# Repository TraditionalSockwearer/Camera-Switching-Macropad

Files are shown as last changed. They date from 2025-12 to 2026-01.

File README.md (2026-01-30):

# Custom OBS Macropad (RP2040)





## Project Status: Completed

## Project Overview
This project is an ongoing engineering initiative to build a custom, 4-key mechanical macropad designed specifically for **Live OBS (Open Broadcaster Software) Scene Switching**.

**The Use Case:**
This device is being built for a local temple's media team. The goal is to provide volunteer operators with a simplified, fail-safe hardware interface to switch camera angles during live services, eliminating the need to interact with complex software UI during a broadcast.

## Planned Features
* **Context-Aware Display:** Integrated **0.91" OLED** to display active camera scenes ("Camera 1 Active", etc.).
* **Synced RGB Feedback:** 4x **SK6812 Mini-E LEDs** that provide colour-coded status indicators synchronised with the active scene.
* **USB HID Interface:** Acts as a standard keyboard sending F13-F16 keys to trigger OBS hotkeys.
* **Compact Form Factor:** Custom 3D-printed enclosure with heat-set inserts for durability.

## Tech Stack
* **Microcontroller:** Seeed Studio XIAO RP2040
* **EDA / PCB:** KiCad 9
* **CAD:** Fusion 360
* **Firmware:** Python (MicroPython) with State Machine logic.
* **Simulation:** Wokwi (Used to validate I2C OLED & NeoPixel logic) and onboard testing.

## Development Roadmap
- [x] **Requirement Analysis:** Defined constraints (silent switches, OLED feedback).
- [x] **Component Sourcing:** Validated BOM (Bill of Materials) for cost/availability.
- [x] **Schematic Capture:** Completed electrical schematic in KiCad.
- [x] **PCB Layout:** Routing tracks and defining edge cuts (In Progress).
- [x] **Prototyping:** 3D printing the case and soldering the first unit.
- [x] **Firmware Prototype:** Created state-machine logic in Wokwi (Simulation).
- [x] **Integration:** Final HID implementation and OBS setup at the venue.

## Repository Structure
```text
/CAD          # STL files (In Progress)
/PCB       # Schematic and PCB files
/Firmware     # Wokwi simulation code and future main.py
```

## CAD Model






Made in Fusion360

## PCB


## Schematic



# BOM

* 4x Cherry MX Switches 

* 2x SK6812 MINI Leds

SK6812 MINI-E RGB 20PCS Link: 

    https://www.aliexpress.com/item/1005008308801366.html

* 1x XIAO RP2040 

Seeed XIAO RP2040 Link: 

    https://www.aliexpress.com/item/1005008200917480.html

* 4x Blank DSA Keycaps

Blank Keycaps 10PCS Link: 
    
    https://www.aliexpress.com/item/1005005514406952.html

* 4x M3x16 Bolt 

M3x16mm Screw Link: 
    
    https://www.aliexpress.com/item/1005008585550992.html

* 4x M3 Heatset 

M3 Heat Set Link: 

    https://www.aliexpress.com/item/1005008897571758.html

* 1x 0.91" 128x32 OLED Display 

OLED Display Link: 

    https://www.aliexpress.com/item/1005008640108394.html

* 1x Case (2 parts: Bottom Case and Cover)

* 1x PCB

I used JLBPCB for PCB
Gerber files are made by opening pcb file. Then press the Files, then Plot, and make sure to press drill and as a single file (it's an option)

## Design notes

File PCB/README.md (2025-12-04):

# Requires Footprint
It is in .gitmodules. However, it doesn't upload so u need to add
Oled display

    https://github.com/gorbachev/KiCad-SSD1306-0.91-OLED-4pin-128x32.pretty/tree/master

Switches

    https://github.com/ai03-2725/MX_V2

OPL_Kicad_Libary

    https://github.com/Seeed-Studio/OPL_Kicad_Library

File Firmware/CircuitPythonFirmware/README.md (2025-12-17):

# The Firmware (KMK + Animated OLED + NeoPixels)
Firmware built on the **Seeed Studio XIAO RP2040** running **CircuitPython** and **KMK Firmware**. It features a 128x32 OLED screen that plays animations when keys are pressed and syncs RGB lighting to the active camera state (Green, Red, Blue, Yellow).

## Feature Status
- [x] **4-Key Matrix Scanning** (KMK Firmware)
- [x] **OLED Support** (SSD1306 via I2C at 0x3C)
- [x] **Custom Animation Extension** (Non-blocking background playback)
- [x] **Responsive Text** (Auto-centering text labels like "CAM 1")
- [x] **RGB LED Sync** (Smooth non-blocking color fades matching the camera state)
- [x] **Onboard LED Control** (Syncs XIAO onboard NeoPixel with external strip)

## Hardware
* **Microcontroller:** Seeed Studio XIAO RP2040
* **Display:** 0.91" OLED (SSD1306 Driver, 128x32 resolution)
* **LEDs:**
    * 1x Onboard WS2812 (NeoPixel)
    * 4x SK6812MINI-E (External Strip connected to Pin D6)
* **Switches:** 4x Mechanical Switches (Directly wired to Pins D0, D1, D2, D3)

## Libraries Used
The following libraries must be installed in the `lib` folder on your `CIRCUITPY` drive:

| Library | Purpose |
| :--- | :--- |
| **KMK Firmware** | Core keyboard firmware handling matrix scanning and keycodes. |
| **adafruit_displayio_ssd1306** | Driver for the OLED display. |
| **adafruit_display_text** | Handles text rendering and label positioning on screen. |
| **adafruit_bus_device** | Core I2C communication helper. |
| **neopixel** | Controls the addressable RGB LEDs. |

> **Note:** Using **CircuitPython 9.x or 10.x** requires built-in library `i2cdisplaybus`.

## 📂 File Structure
`CIRCUITPY` drive should look like this:

```text
CIRCUITPY/
├── lib/
│   ├── kmk/
│   ├── adafruit_display_text/
│   ├── adafruit_displayio_ssd1306.mpy
│   ├── adafruit_bus_device/
│   └── neopixel.mpy
├── code.py              # Main entry point (Keyboard setup)
├── movie_extension.py   # Custom extension for Animation & LEDs
└── movie_data.py        # Raw bitmap data for the animation

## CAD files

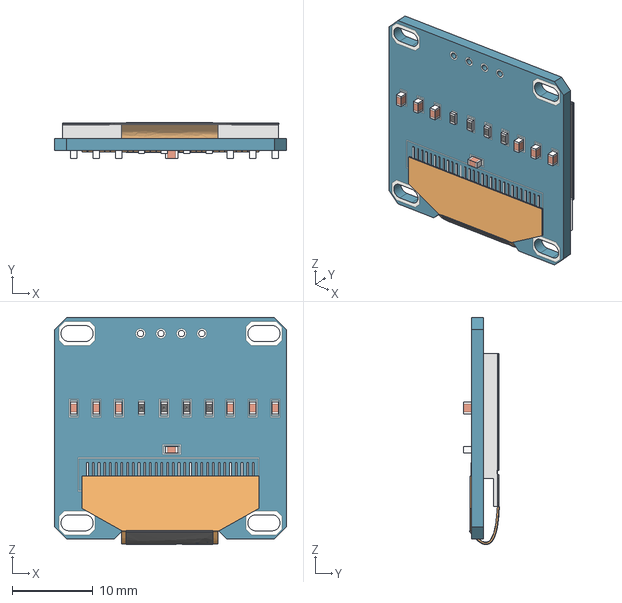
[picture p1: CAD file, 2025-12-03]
Case/Combined look/SSD1306.stp
28.8 x 4.46 x 28.2 mm

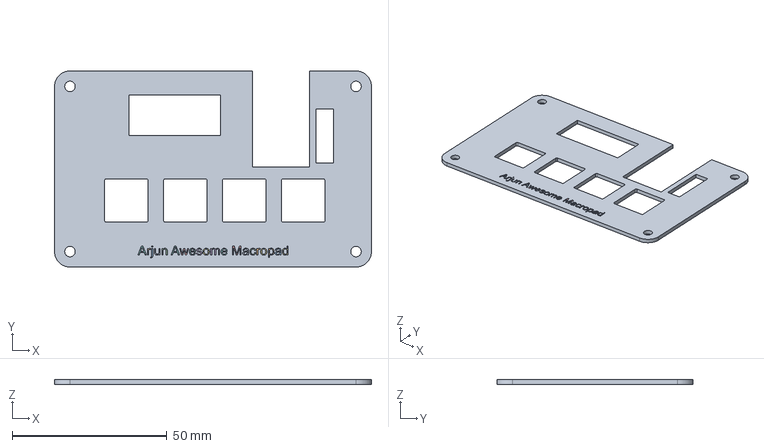
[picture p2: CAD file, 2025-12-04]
Case/The Shell/TopCase.step
102.4 x 63.4 x 1.50 mm

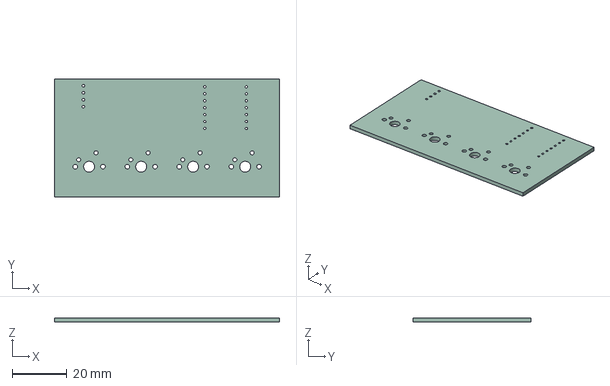
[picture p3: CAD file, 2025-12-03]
PCB/MyPCB.step
82.4 x 43.3 x 1.51 mm

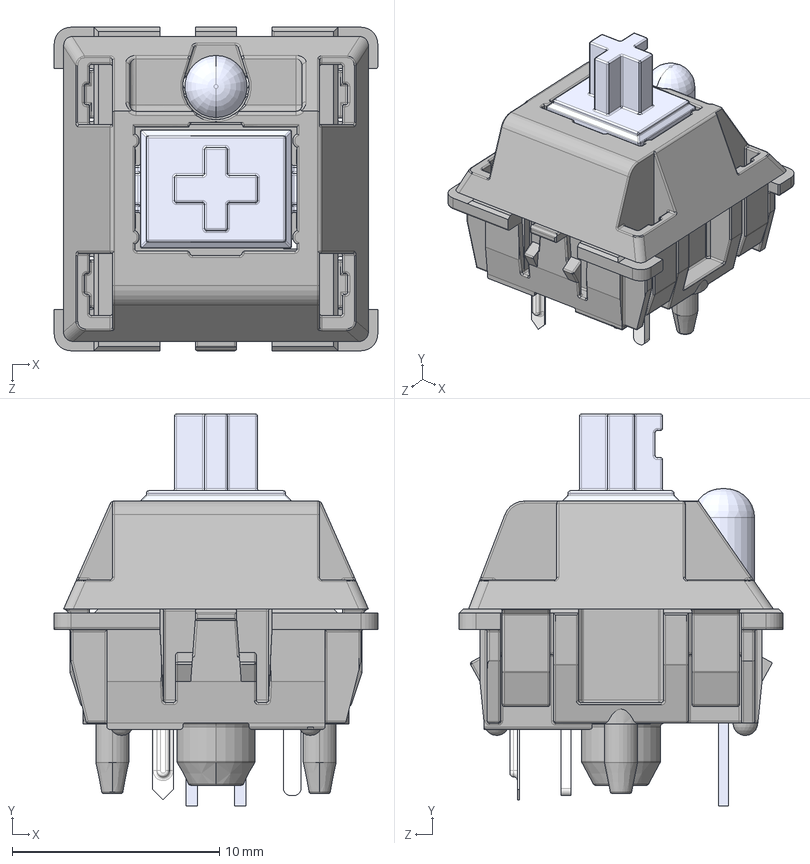
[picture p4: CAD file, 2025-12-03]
Case/Combined look/MX .STEP
15.6 x 18.9 x 15.6 mm
MX 轴 按键′_ü___¨1
MX 轴 轴体áì_¨￠¨__
MX粣 拸簽LEDLEDLED
MX轴 轴体 底部 μ×2__默认_á2____è_
针脚___默认__è_

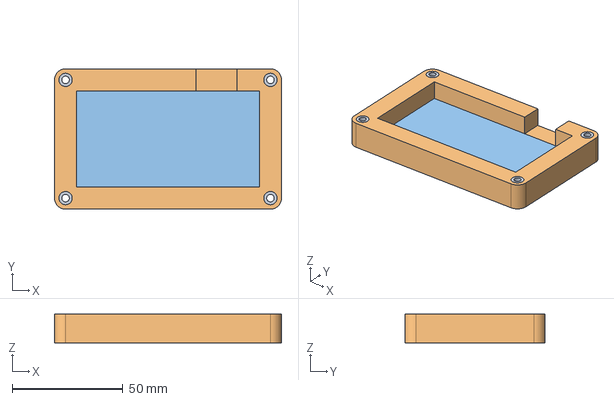
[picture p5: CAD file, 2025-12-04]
Case/The Shell/BottomCase.step
102.4 x 63.4 x 13.0 mm

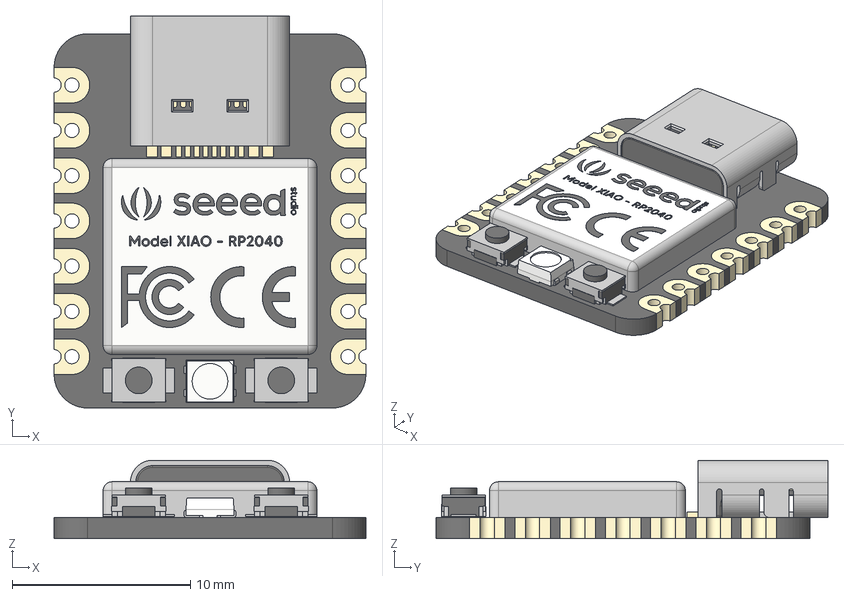
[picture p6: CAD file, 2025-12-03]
Case/Combined look/Seeed Studio XIAO RP2040 v26.step
17.5 x 22.0 x 4.40 mm
type-c v2
smd_button v3
DOUT
DIN
VSS
VDD
smd_button v3(Mirror)

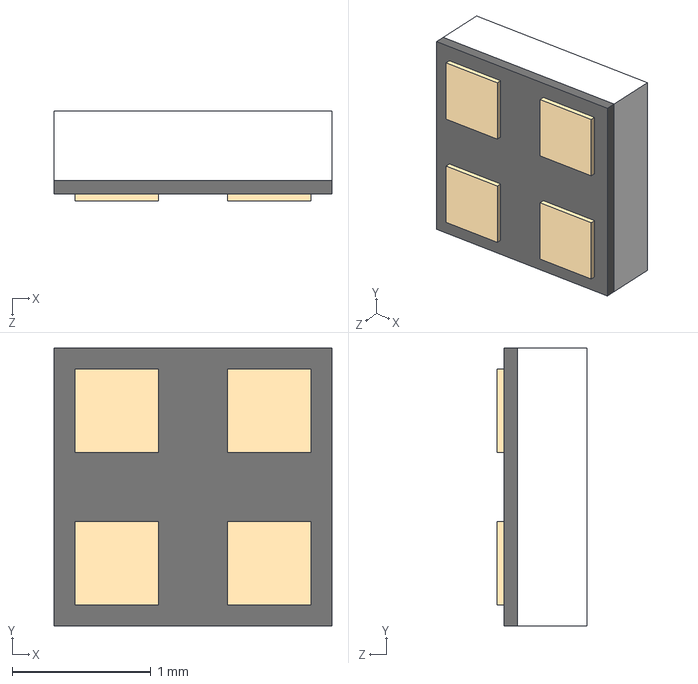
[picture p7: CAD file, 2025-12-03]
Case/Combined look/SK6812-EC20.STEP
2.00 x 2.00 x 0.65 mm

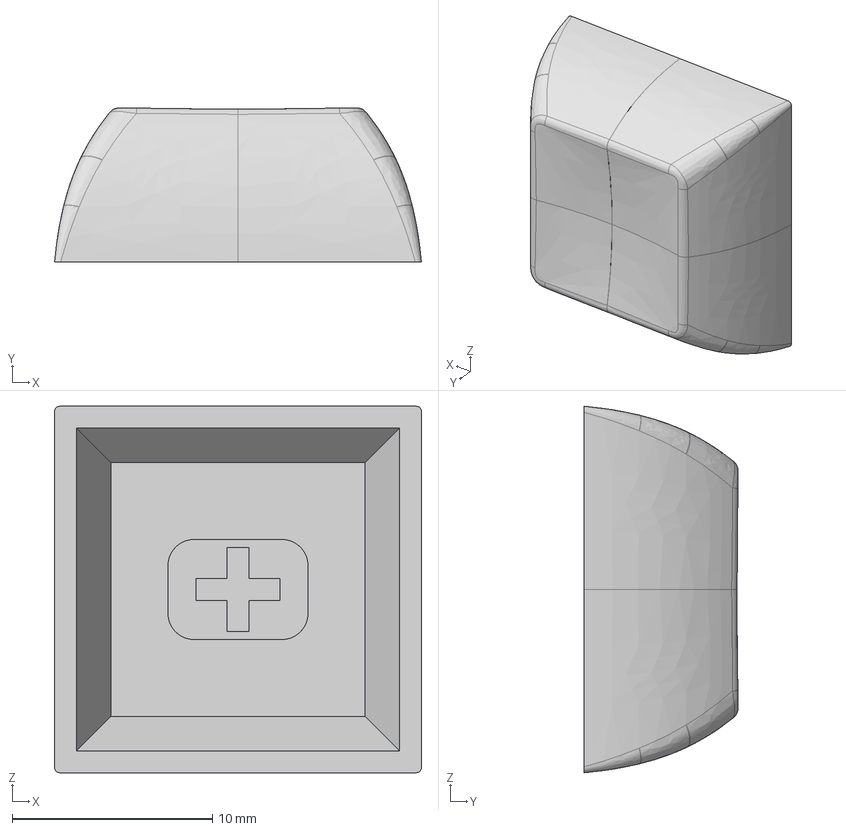
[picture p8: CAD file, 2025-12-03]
Case/Combined look/DSA_Keycap_CherryMX.step
18.3 x 7.69 x 18.3 mm

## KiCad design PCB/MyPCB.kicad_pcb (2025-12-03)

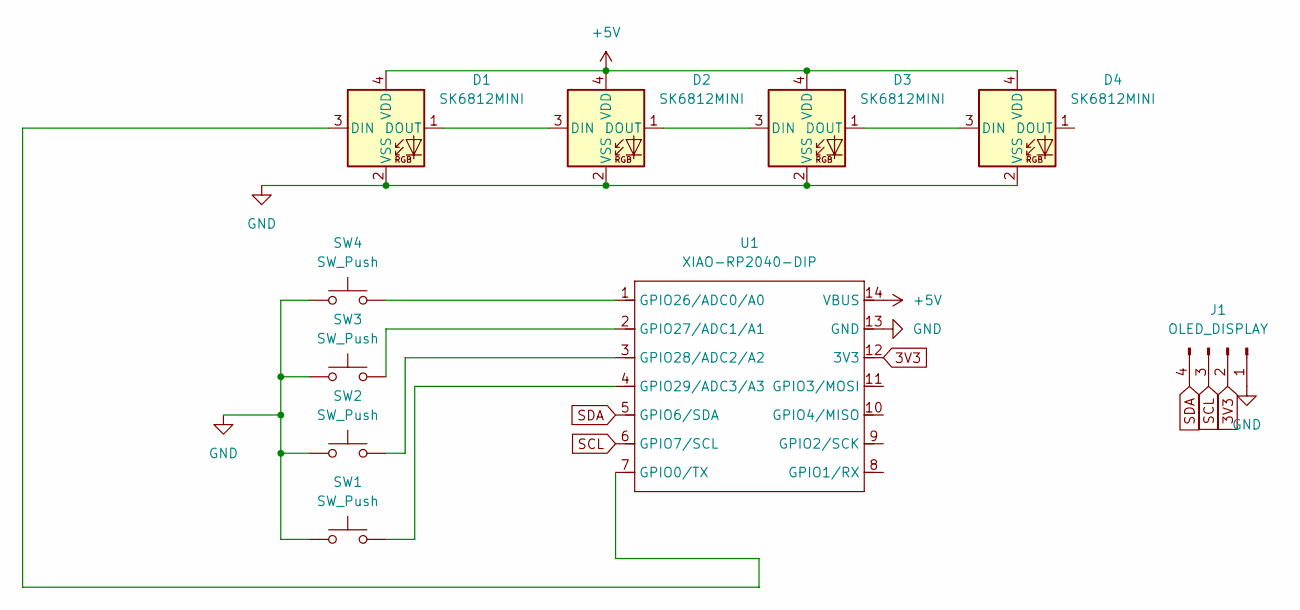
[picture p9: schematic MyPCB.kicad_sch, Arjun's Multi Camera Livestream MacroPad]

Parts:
D1, D2, D3, D4: SK6812MINI; LED_SK6812MINI_PLCC4_3.5x3.5mm_P1.75mm
J1: OLED_DISPLAY; SSD1306-0.91-OLED-4pin-128x32
SW1, SW2, SW3, SW4: SW_Push; SW_Cherry_MX_1.00u_PCB
U1: XIAO-RP2040-DIP

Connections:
3V3: J1.2, U1.12 (3V3)
+5V: D1.4 (VDD), D2.4 (VDD), D3.4 (VDD), D4.4 (VDD), U1.14 (VBUS)
GND: D1.2 (VSS), D2.2 (VSS), D3.2 (VSS), D4.2 (VSS), J1.1, SW1.1, SW2.1, SW3.1, SW4.1, U1.13 (GND)
unnamed: D1.3 (DIN), U1.7 (GPIO0/TX)
unnamed: D1.1 (DOUT), D2.3 (DIN)
unnamed: D2.1 (DOUT), D3.3 (DIN)
unnamed: D3.1 (DOUT), D4.3 (DIN)
unnamed: SW4.2, U1.1 (GPIO26/ADC0/A0)
unnamed: SW3.2, U1.2 (GPIO27/ADC1/A1)
unnamed: SW2.2, U1.3 (GPIO28/ADC2/A2)
unnamed: SW1.2, U1.4 (GPIO29/ADC3/A3)
SCL: J1.3, U1.6 (GPIO7/SCL)
SDA: J1.4, U1.5 (GPIO6/SDA)

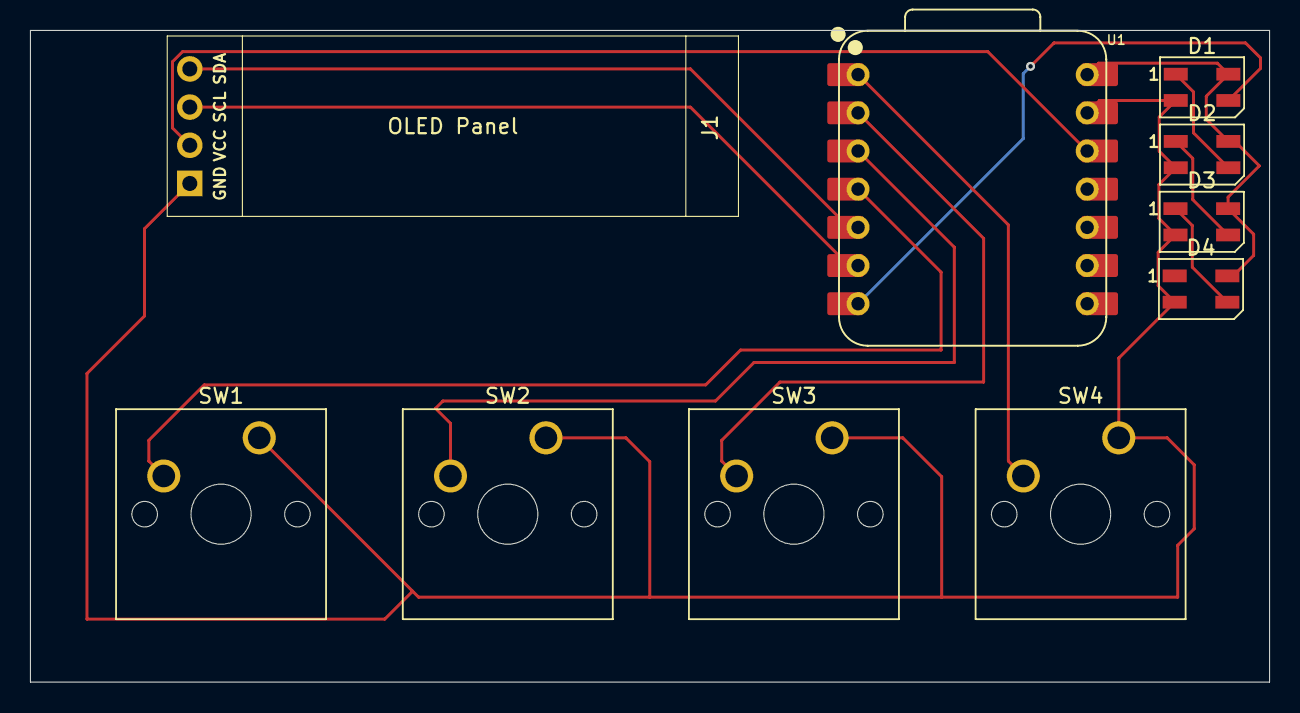
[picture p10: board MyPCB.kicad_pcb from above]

Board: 2 copper layers, 82.4 x 43.3 mm, 10 parts (0 on the bottom side), 13 nets.

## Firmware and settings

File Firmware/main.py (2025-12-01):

"""
Macropad
"""

from machine import Pin, I2C
from ssd1306 import SSD1306_I2C
import neopixel 
import utime

WIDTH  = 128
HEIGHT = 64
SCL_PIN = 27
SDA_PIN = 26  
BTN_PINS = [15, 14, 13, 12] 
LED_PIN = 7     
NUM_LEDS = 4 

FADE_STEPS = 20     # Higher = Smoother
FADE_DELAY = 0.01   # Delay between steps

COLORS = [
    (0, 255, 0),    # Cam 1: All Green
    (255, 0, 0),    # Cam 2: All Red
    (0, 0, 255),    # Cam 3: All Blue
    (255, 255, 0)   # Cam 4: All Yellow
]

def init_hardware():
    i2c = I2C(1, scl=Pin(SCL_PIN), sda=Pin(SDA_PIN), freq=400000)
    oled = SSD1306_I2C(WIDTH, HEIGHT, i2c)
    
    buttons = []
    for p in BTN_PINS:
        buttons.append(Pin(p, Pin.IN, Pin.PULL_UP))

    leds = neopixel.NeoPixel(Pin(LED_PIN), NUM_LEDS)
    return oled, buttons, leds

def animate_sync_fade(leds, target_color):

    start_r, start_g, start_b = leds[0]
    target_r, target_g, target_b = target_color
    
    for step in range(1, FADE_STEPS + 1):
        fraction = step / FADE_STEPS
        
        r = int(start_r + (target_r - start_r) * fraction)
        g = int(start_g + (target_g - start_g) * fraction)
        b = int(start_b + (target_b - start_b) * fraction)
        
        leds.fill((r, g, b)) 
        leds.write()
        
        utime.sleep(FADE_DELAY)

def update_status(oled, leds, active_cam):
    # A. Update Screen
    oled.fill(0)
    oled.text("OBS MACROPAD", 10, 0)
    oled.hline(0, 10, 128, 1) 
    oled.text(f"Camera {active_cam} Active", 5, 30)
    
    # Draw box
    x_pos = 5 + ((active_cam - 1) * 30)
    oled.fill_rect(x_pos, 45, 20, 10, 1)
    oled.show()

    # Get the color for this camera
    new_color = COLORS[active_cam - 1]
    
    print(f"Fading all LEDs to Camera {active_cam} Color...")
    animate_sync_fade(leds, new_color)


def main():
    oled, buttons, leds = init_hardware()
    
    oled.text("System Ready.", 5, 0)
    oled.show()
    
    # Start with all LEDs off
    leds.fill((0,0,0))
    leds.write()
    
    # Startup Flash (White)
    utime.sleep(0.5)
    animate_sync_fade(leds, (50, 50, 50))
    animate_sync_fade(leds, (0, 0, 0))

    current_state = 0 

    while True:
        for i in range(4):
            if buttons[i].value() == 0:
                cam_id = i + 1 
                
                if current_state != cam_id:
                    current_state = cam_id
                    update_status(oled, leds, current_state)
                
                utime.sleep(0.1) 

        utime.sleep(0.05)

if __name__ == '__main__':
    main()

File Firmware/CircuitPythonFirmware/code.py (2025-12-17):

import board
import busio
import displayio
import i2cdisplaybus
import adafruit_displayio_ssd1306

from kmk.kmk_keyboard import KMKKeyboard
from kmk.keys import KC, make_key
from kmk.scanners.keypad import KeysScanner
from movie_extension import MovieExtension


displayio.release_displays()
i2c = busio.I2C(board.D5, board.D4)
display_bus = i2cdisplaybus.I2CDisplayBus(i2c, device_address=0x3C)
display = adafruit_displayio_ssd1306.SSD1306(display_bus, width=128, height=32)

keyboard = KMKKeyboard()
movie_ext = MovieExtension(display=display)
keyboard.extensions.append(movie_ext)

def press_0(key, keyboard, *args):
    # Cam 1: Green (0, 255, 0)
    movie_ext.play_animation("CAM 1", (0, 255, 0))
    keyboard.tap_key(KC.A)

def press_1(key, keyboard, *args):
    # Cam 2: Red (255, 0, 0)
    movie_ext.play_animation("CAM 2", (255, 0, 0))
    keyboard.tap_key(KC.B)

def press_2(key, keyboard, *args):
    # Cam 3: Blue (0, 0, 255)
    movie_ext.play_animation("CAM 3", (0, 0, 255))
    keyboard.tap_key(KC.C)

def press_3(key, keyboard, *args):
    # Cam 4: Yellow (255, 255, 0)
    movie_ext.play_animation("CAM 4", (255, 255, 0))
    keyboard.tap_key(KC.D)

# 4. KEYMAP
CUST_A = make_key(names=('CAM_1',), on_press=press_0)
CUST_B = make_key(names=('CAM_2',), on_press=press_1)
CUST_C = make_key(names=('CAM_3',), on_press=press_2)
CUST_D = make_key(names=('CAM_4',), on_press=press_3)

keyboard.matrix = KeysScanner(
    pins=(board.D0, board.D1, board.D2, board.D3),
    value_when_pressed=False,
    pull=True,
)

keyboard.keymap = [
    [CUST_A, CUST_B, CUST_C, CUST_D],
]

if __name__ == '__main__':
    keyboard.go()

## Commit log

2025-11-29 Update PCB Design
    [MyPCB.kicad_sch]
2025-11-30 Finished PCB
    [1_01 Table of Contents.kicad_sch, 2_02 Block Diagram.kicad_sch, 3_03 Power IN & MCU GPIOs.kicad_sch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]
2025-11-30 Fix part 2
    [1_01 Table of Contents.kicad_sch, 2_02 Block Diagram.kicad_sch, 3_03 Power IN & MCU GPIOs.kicad_sch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]
2025-12-01 Started main firmware without module
    [MyPCB.kicad_pcb, MyPCB.kicad_sch]
2025-12-03 finish case
    [BottomCase.step, DSA_Keycap_CherryMX.step, Fullybuiltcase.f3z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]
2025-12-04 Sorting Directories and adding .step files
    [BottomCase.step, DSA_Keycap_CherryMX.step, Fullybuiltcase.f3z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]
2025-12-17 First Revision of code
    Keys are fully functioning will need changing on second revision animation works and screen works. LED are not working and libraries for them haven't been uploaded
    [code.py, movie_data.py, movie_extension.py]
2026-01-30 Move Gerber files to PCB/Gerber and clean backups
    Relocated all Gerber and related output files from PCB/ to PCB/Gerber for better organization. Removed old backup ZIP files and a KiCad lock file to clean up the repository.
    [MyPCB-B_Cu.gbr, MyPCB-B_Mask.gbr, MyPCB-B_Paste.gbr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]
